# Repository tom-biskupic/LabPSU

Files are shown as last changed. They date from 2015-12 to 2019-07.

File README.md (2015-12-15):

# LabPSU
Open Source Lab Power Supply

This project is to create an open source modular lab power supply. The power supply is designed to:

* Provide between 0-15V @ 5A and 15-30V @ 3A
* Provide current limiting
* Voltage to be settable to within 1mV and current limit to 1mA resolution.
* Voltage/current readback to 1mV and 1mA with low temperature drift.
* Limit heat loss through the use of a pre-regulator. The pre-regulator uses an SCR and MOSFET arrangement to reduce noise (switches at a low frequency)
* Digitally controllable via a Raspberry PI and touch-screen interface.
* Multiple channels (designed for 3).
* Each channel is isolated and can be paralleled or put in series.
* Each channel uses its own torroidal transformer.

A Blog documenting the development of the project can be found here http://wahz.blogspot.com.au/2015/03/lab-power-supply-project.html

The major components used in the project are:

* IRFP044N N-channel MOSFET as the pass device. http://www.irf.com/product-info/datasheets/data/irfp044n.pdf
* IRF5210 P-channel MOSFET used to switch the input in the pre-regulator http://www.irf.com/product-info/datasheets/data/irf5210.pdf
* MCR-100 SCR http://www.onsemi.com/pub_link/Collateral/MCR100-D.PDF
* LT1639 Op Amps used in the control loop. http://www.linear.com/product/LT1639
* LT1716 Comparator used in the pre-regulator http://cds.linear.com/docs/en/datasheet/1716fa.pdf
* LTC2050 Op Amp used for current sense amplifier. http://www.linear.com/product/LTC2050
* AD5689R DAC with built in 2ppm/degree reference as main output voltage/current DAC. http://www.analog.com/media/en/technical-documentation/data-sheets/AD5689_5687.pdf
* AD7705 ADC used to read output voltage/current http://www.analog.com/media/en/technical-documentation/data-sheets/AD7705_7706.pdf
* ATMEGA328P Used as the main controller
* ADUM1201 dual channel isolator used to isolate the USB interface from the rest of the module http://www.analog.com/media/en/technical-documentation/data-sheets/ADuM1200_1201.pdf
* MCP2200 USB to serial converter http://www.microchip.com/wwwproducts/devices.aspx?dDocName=en546923

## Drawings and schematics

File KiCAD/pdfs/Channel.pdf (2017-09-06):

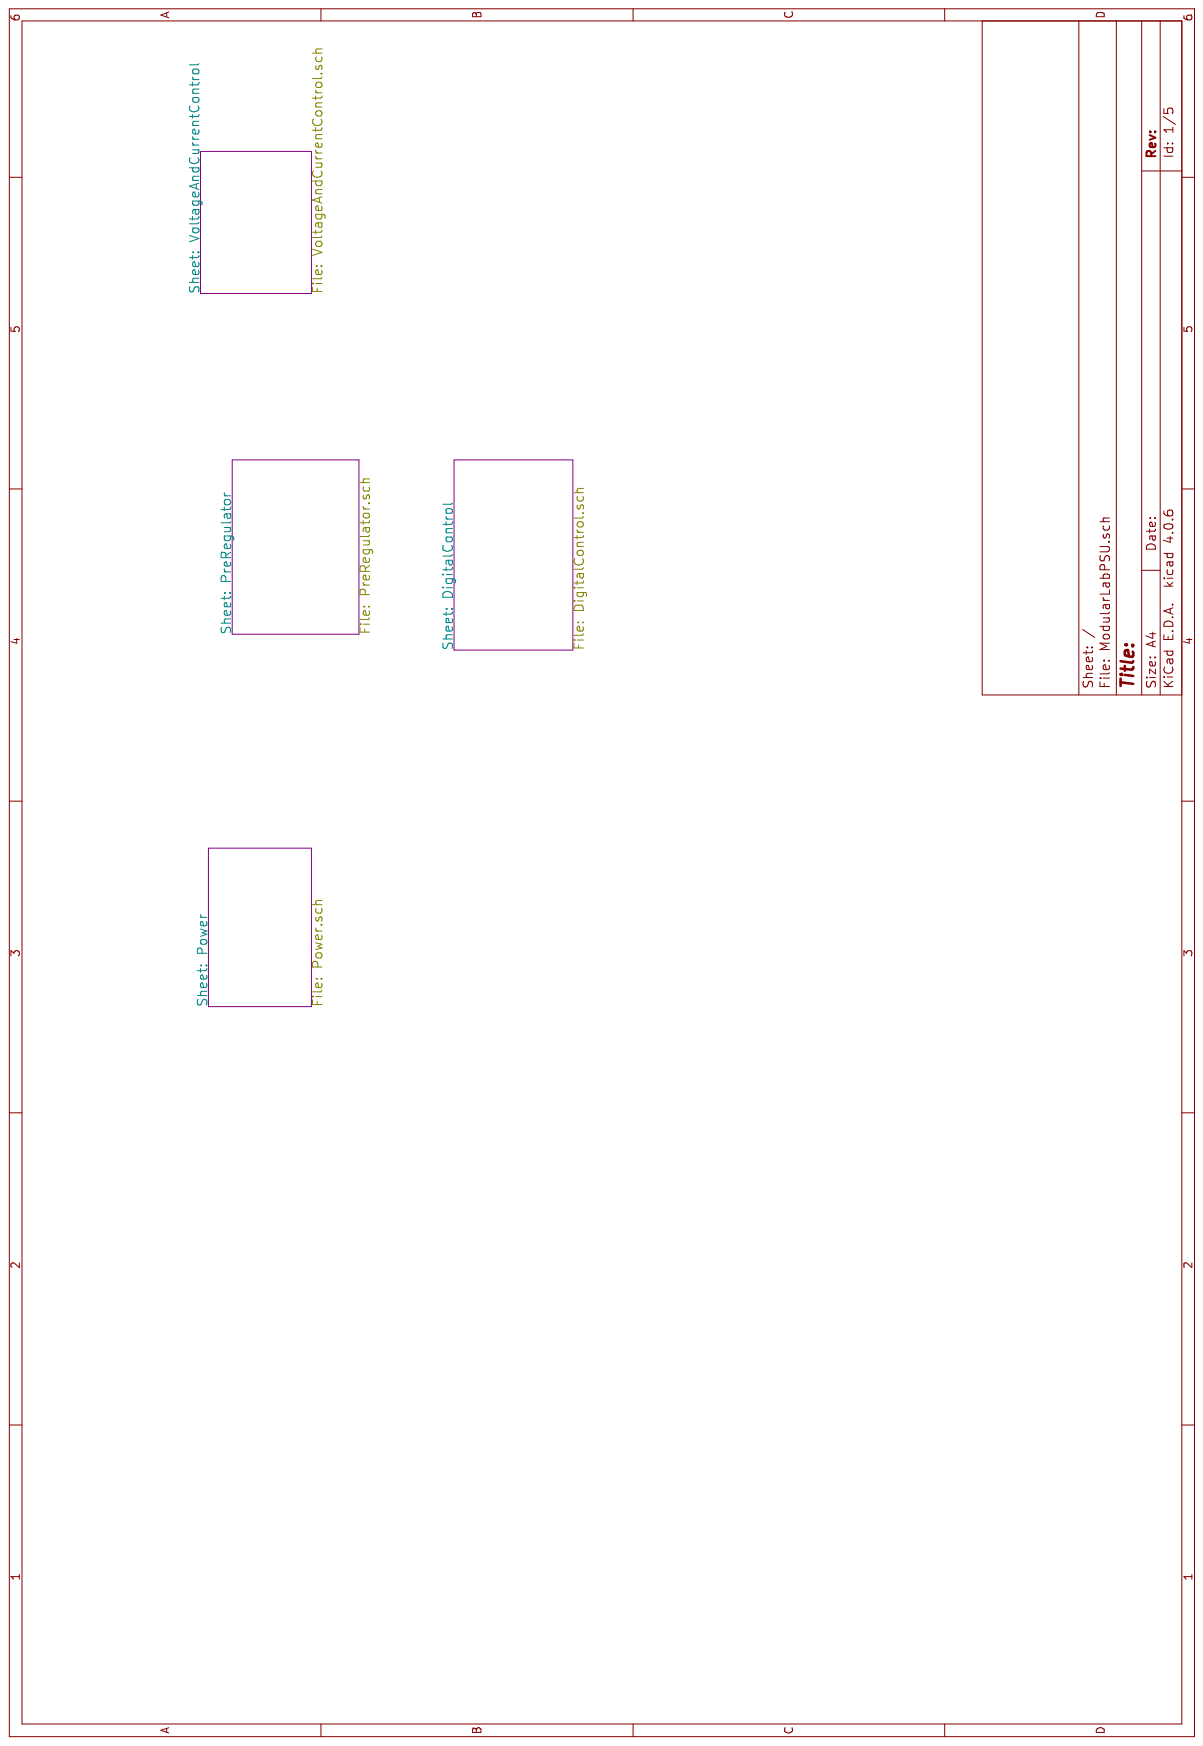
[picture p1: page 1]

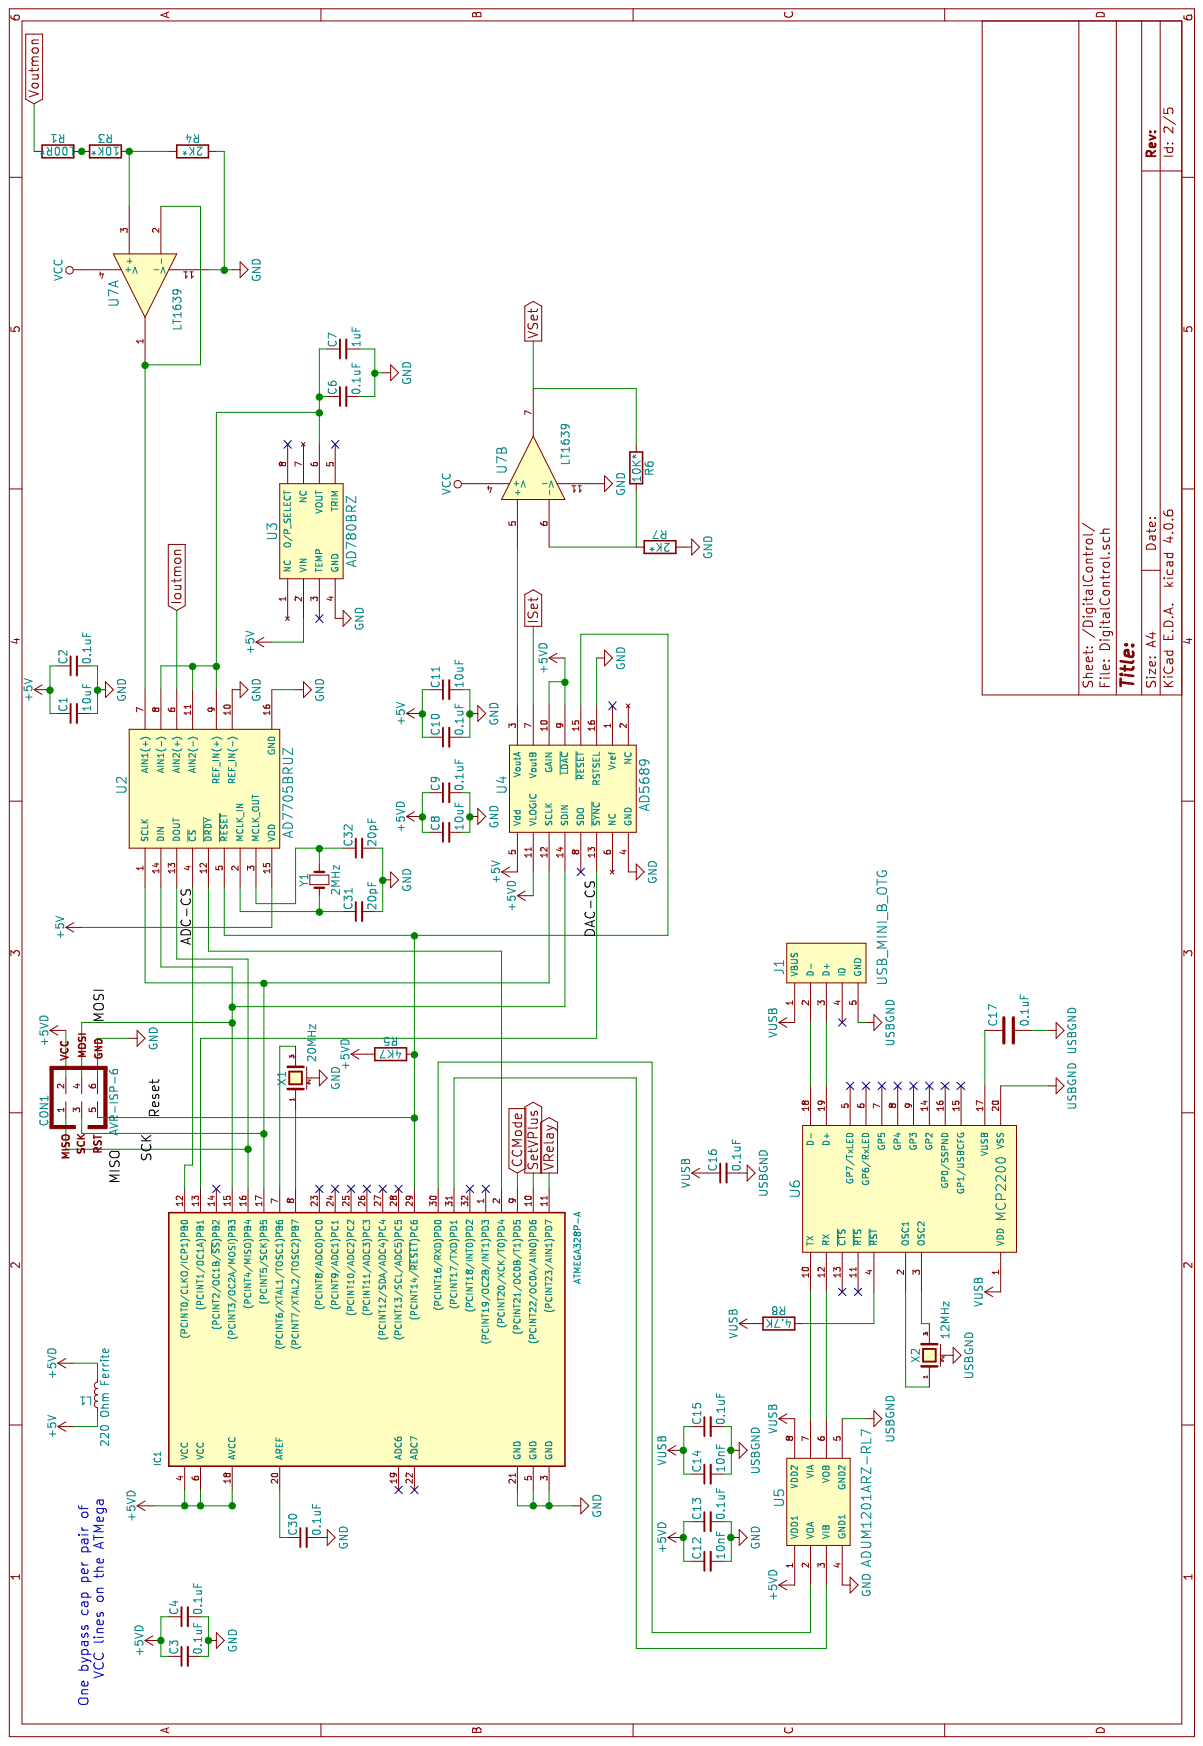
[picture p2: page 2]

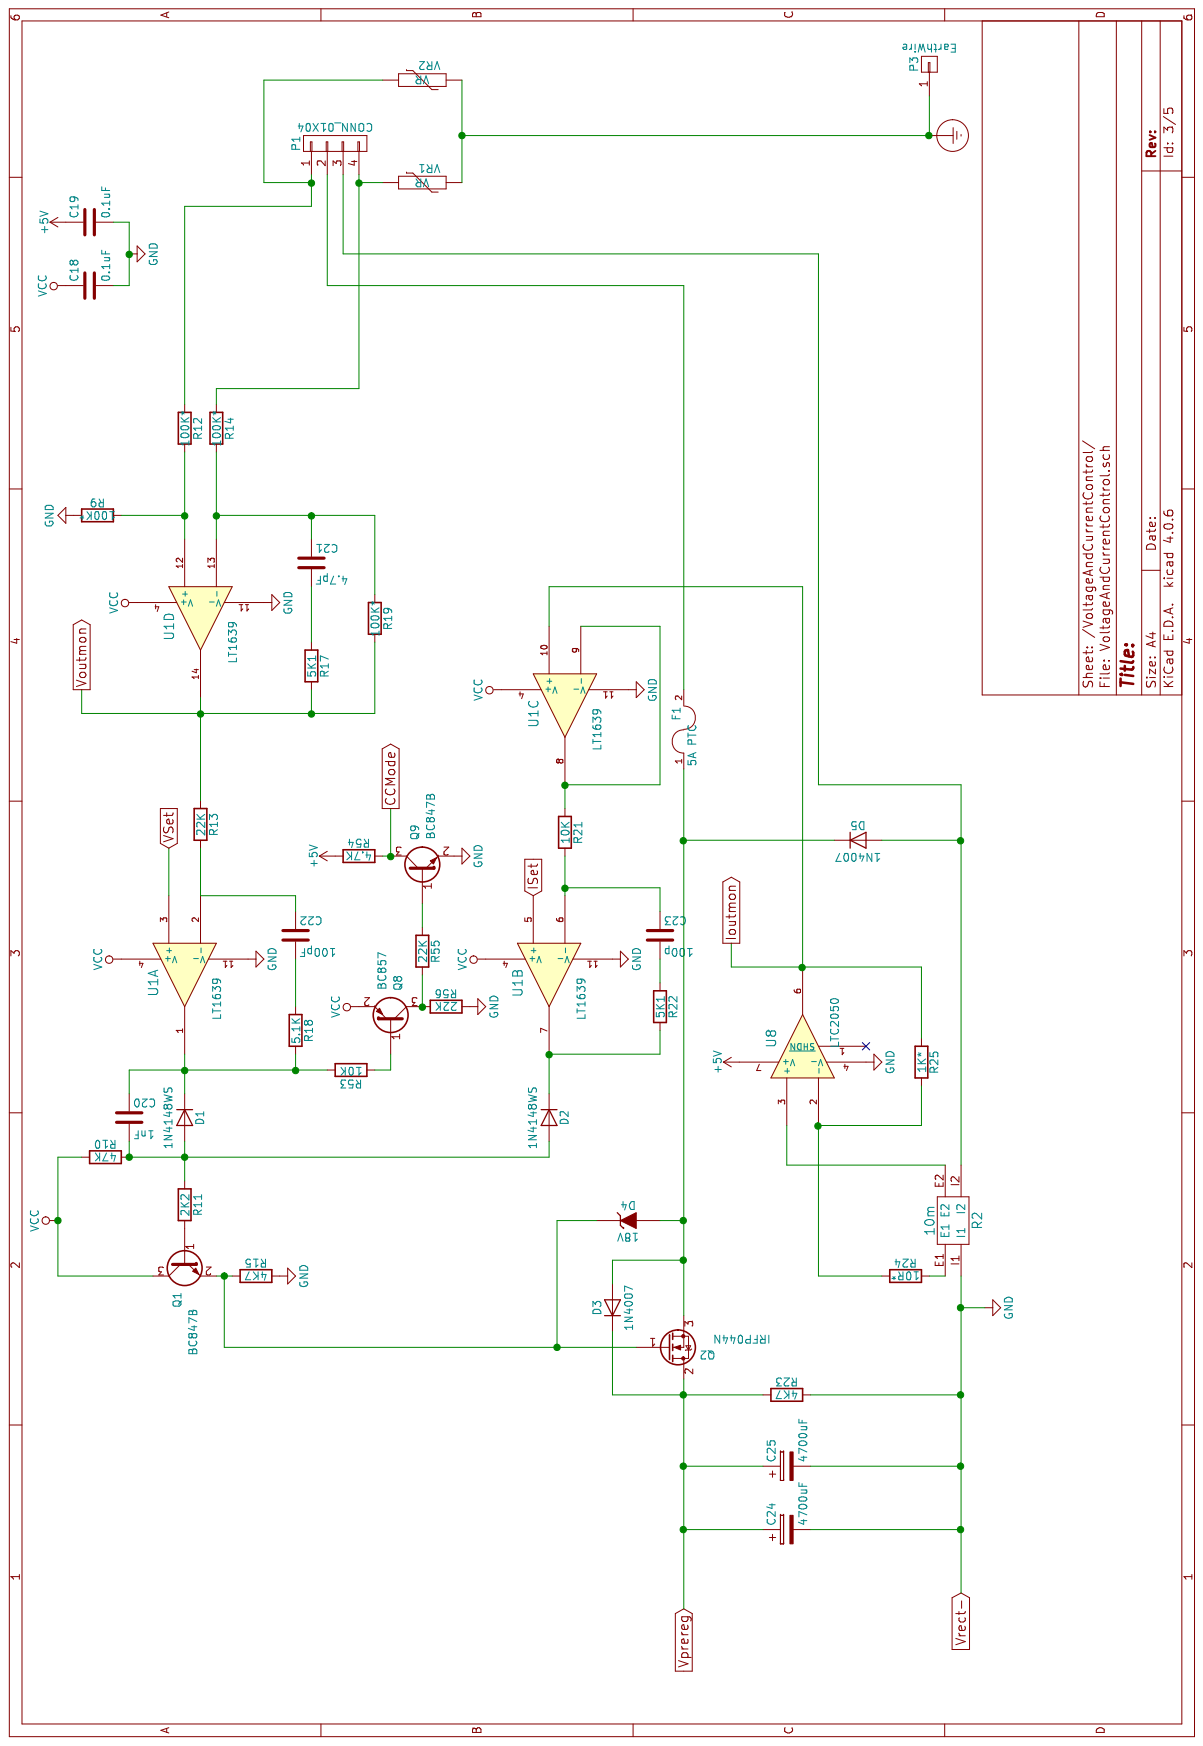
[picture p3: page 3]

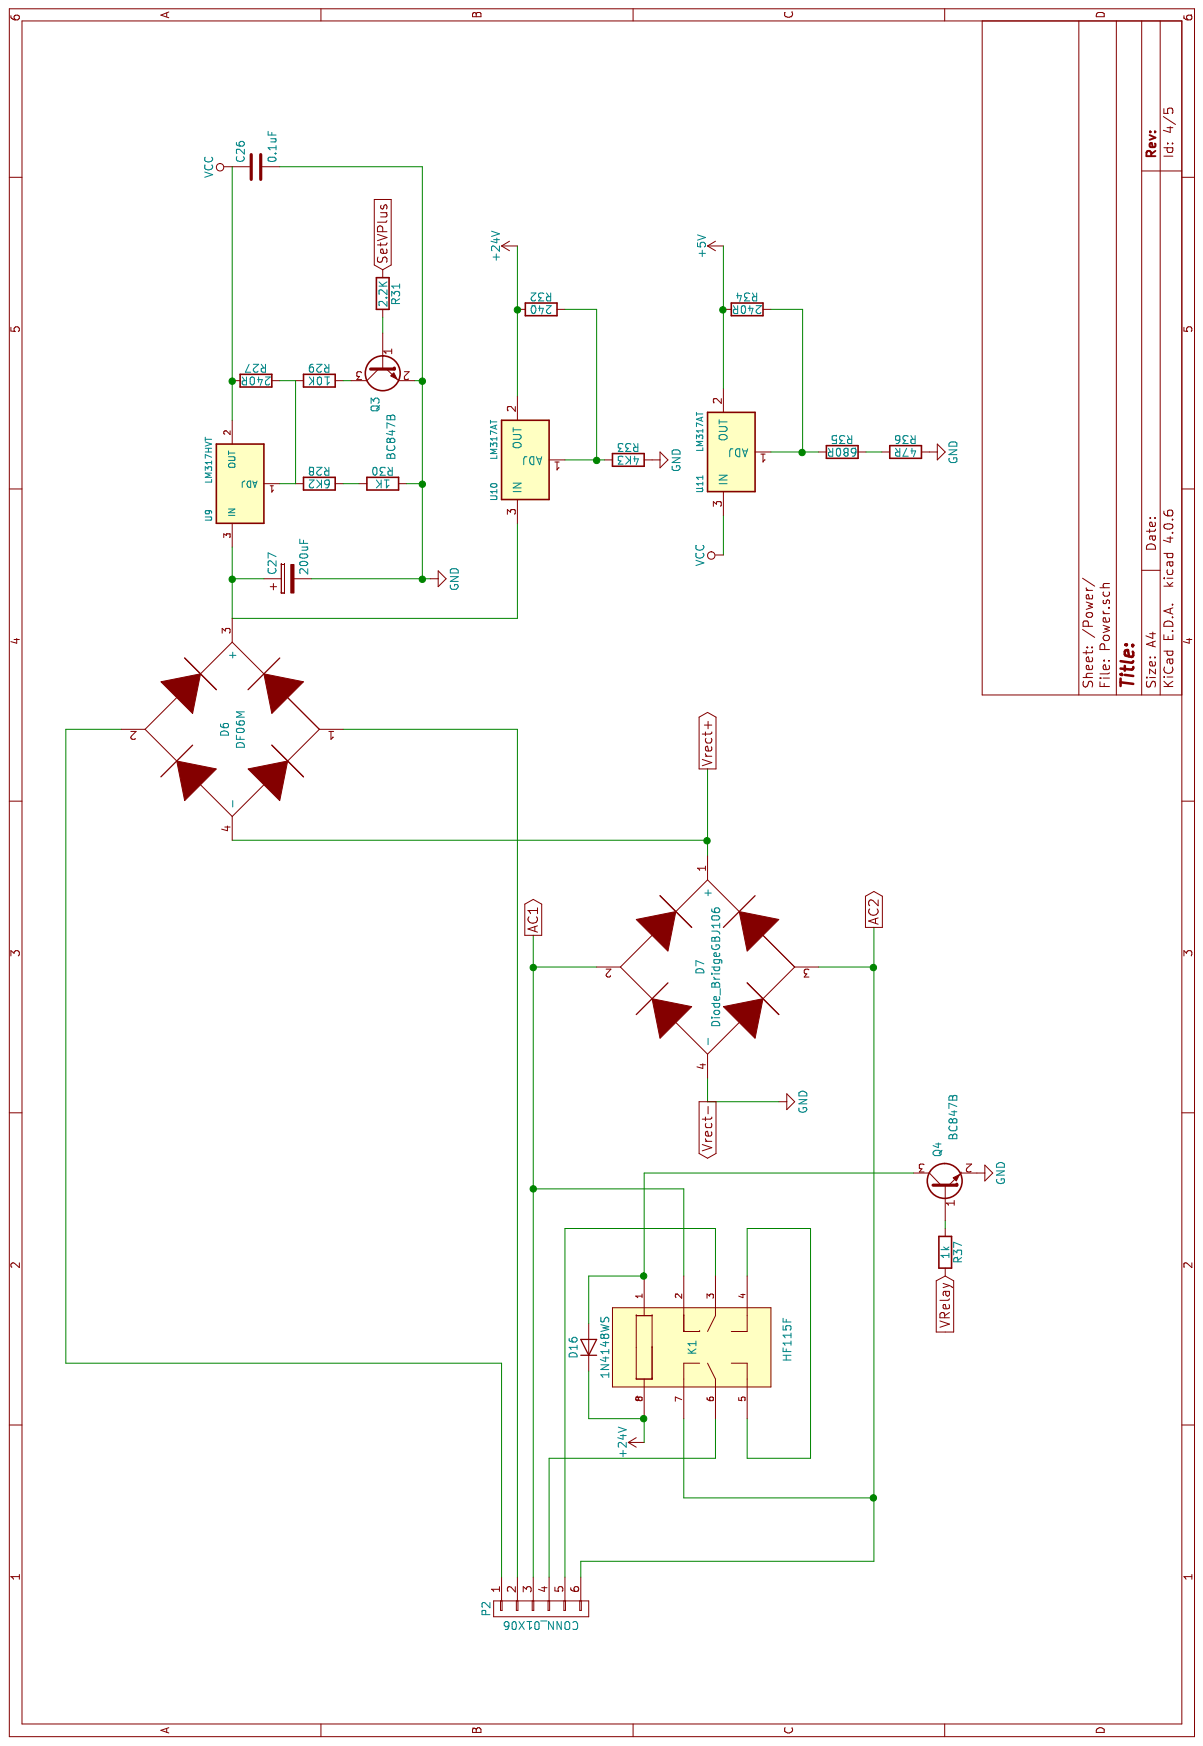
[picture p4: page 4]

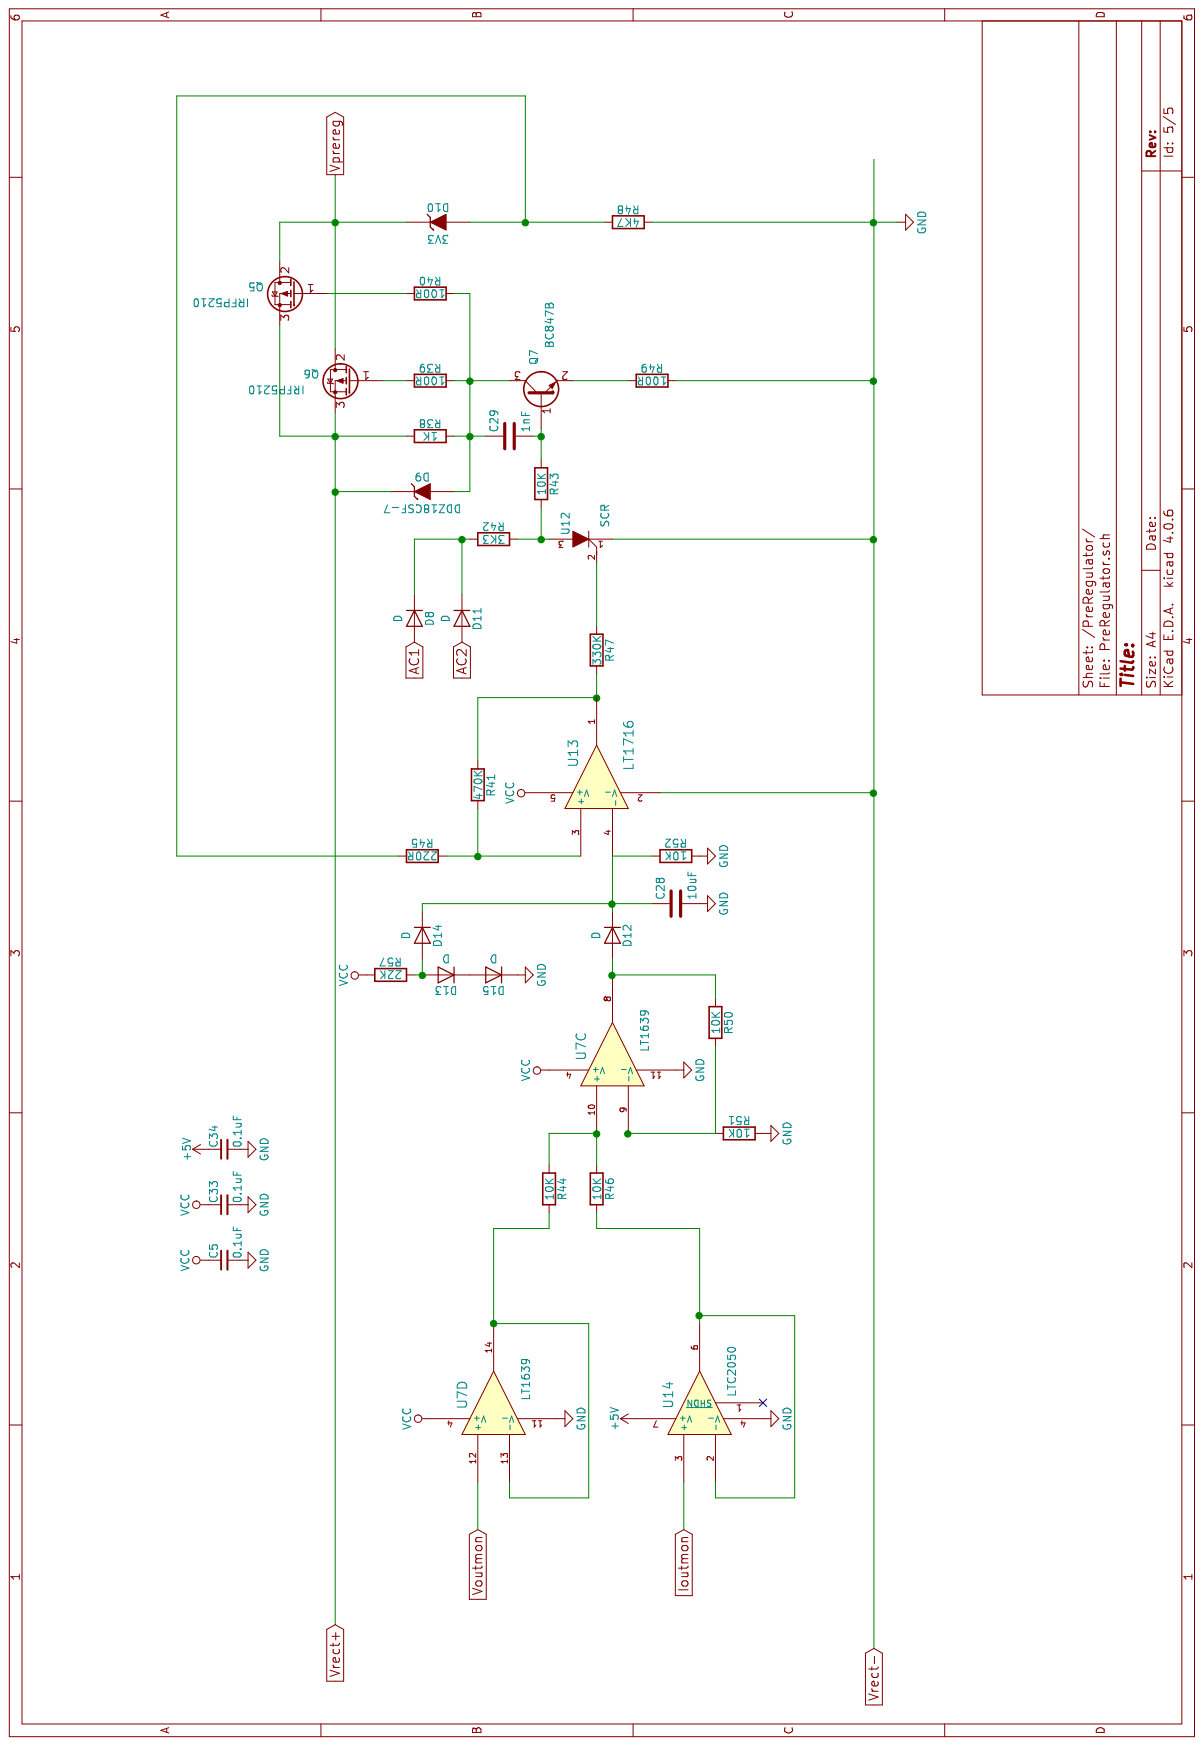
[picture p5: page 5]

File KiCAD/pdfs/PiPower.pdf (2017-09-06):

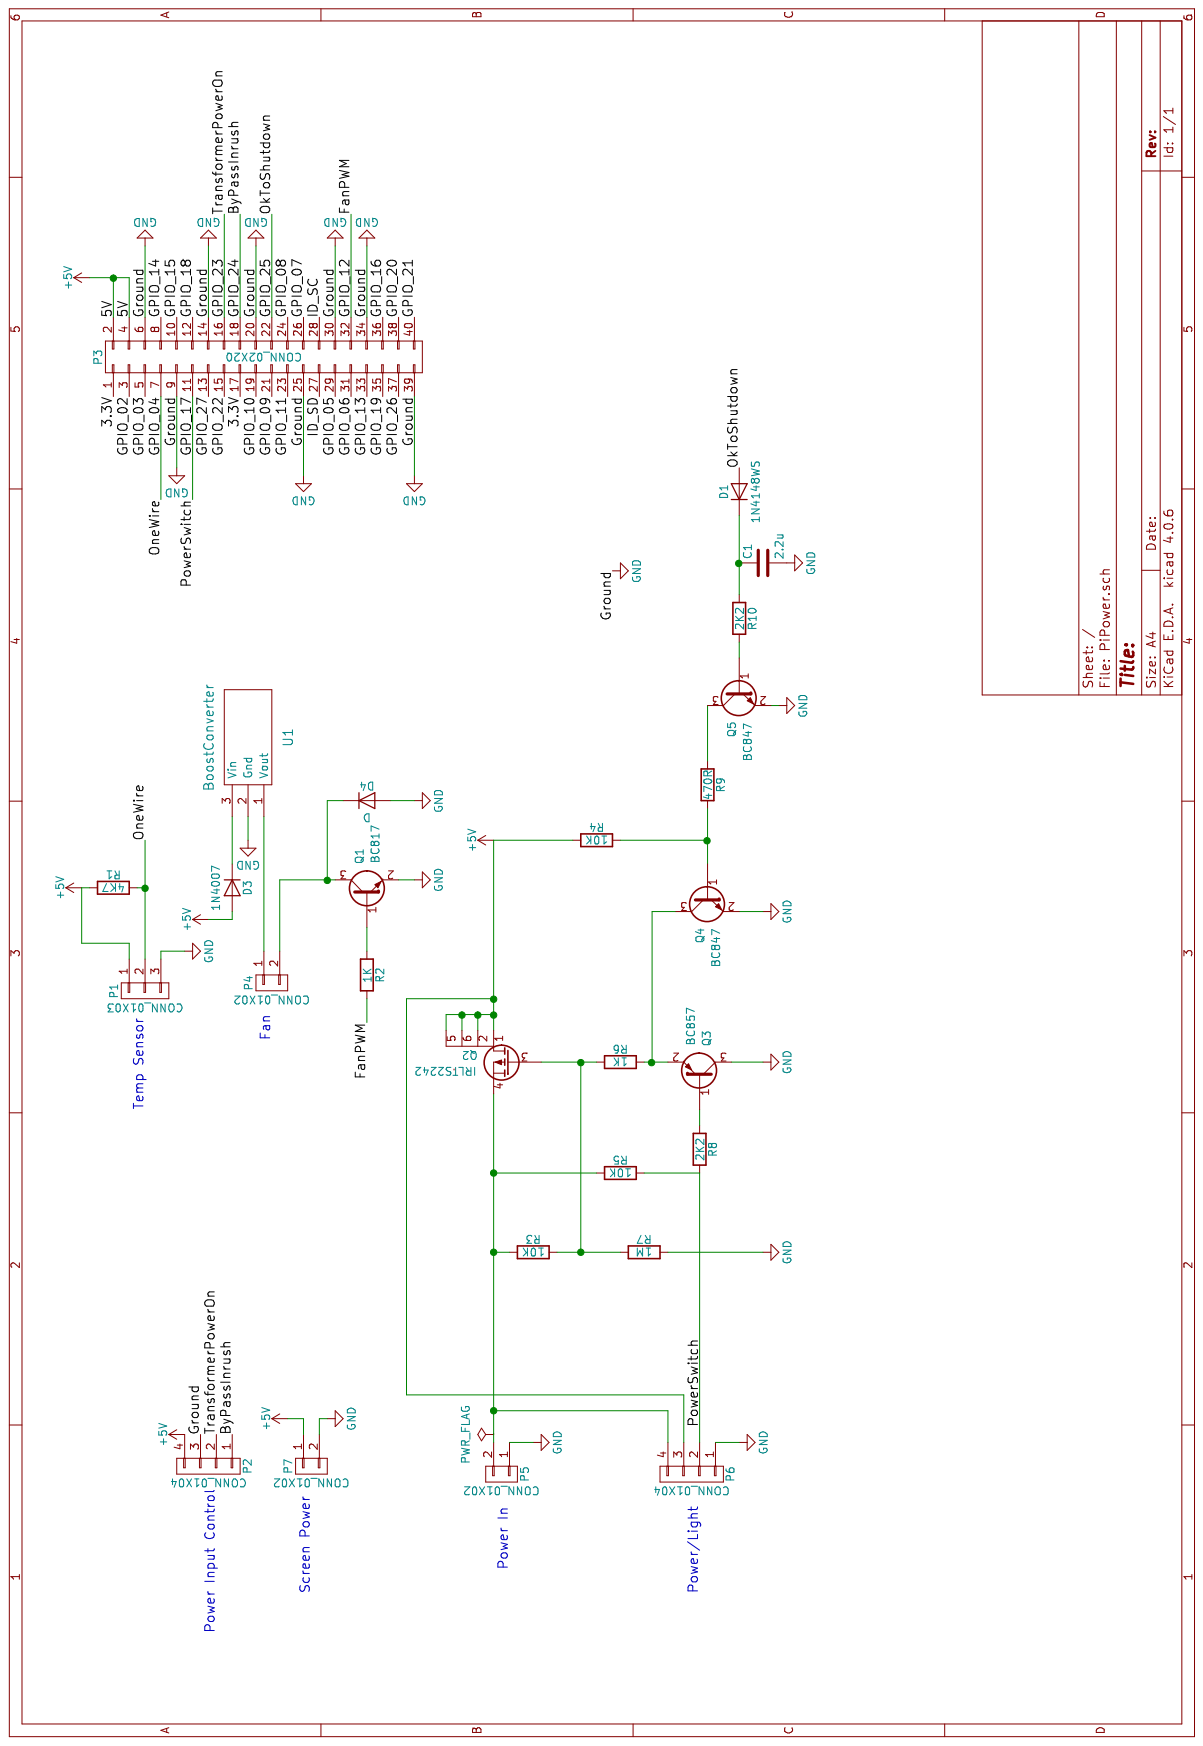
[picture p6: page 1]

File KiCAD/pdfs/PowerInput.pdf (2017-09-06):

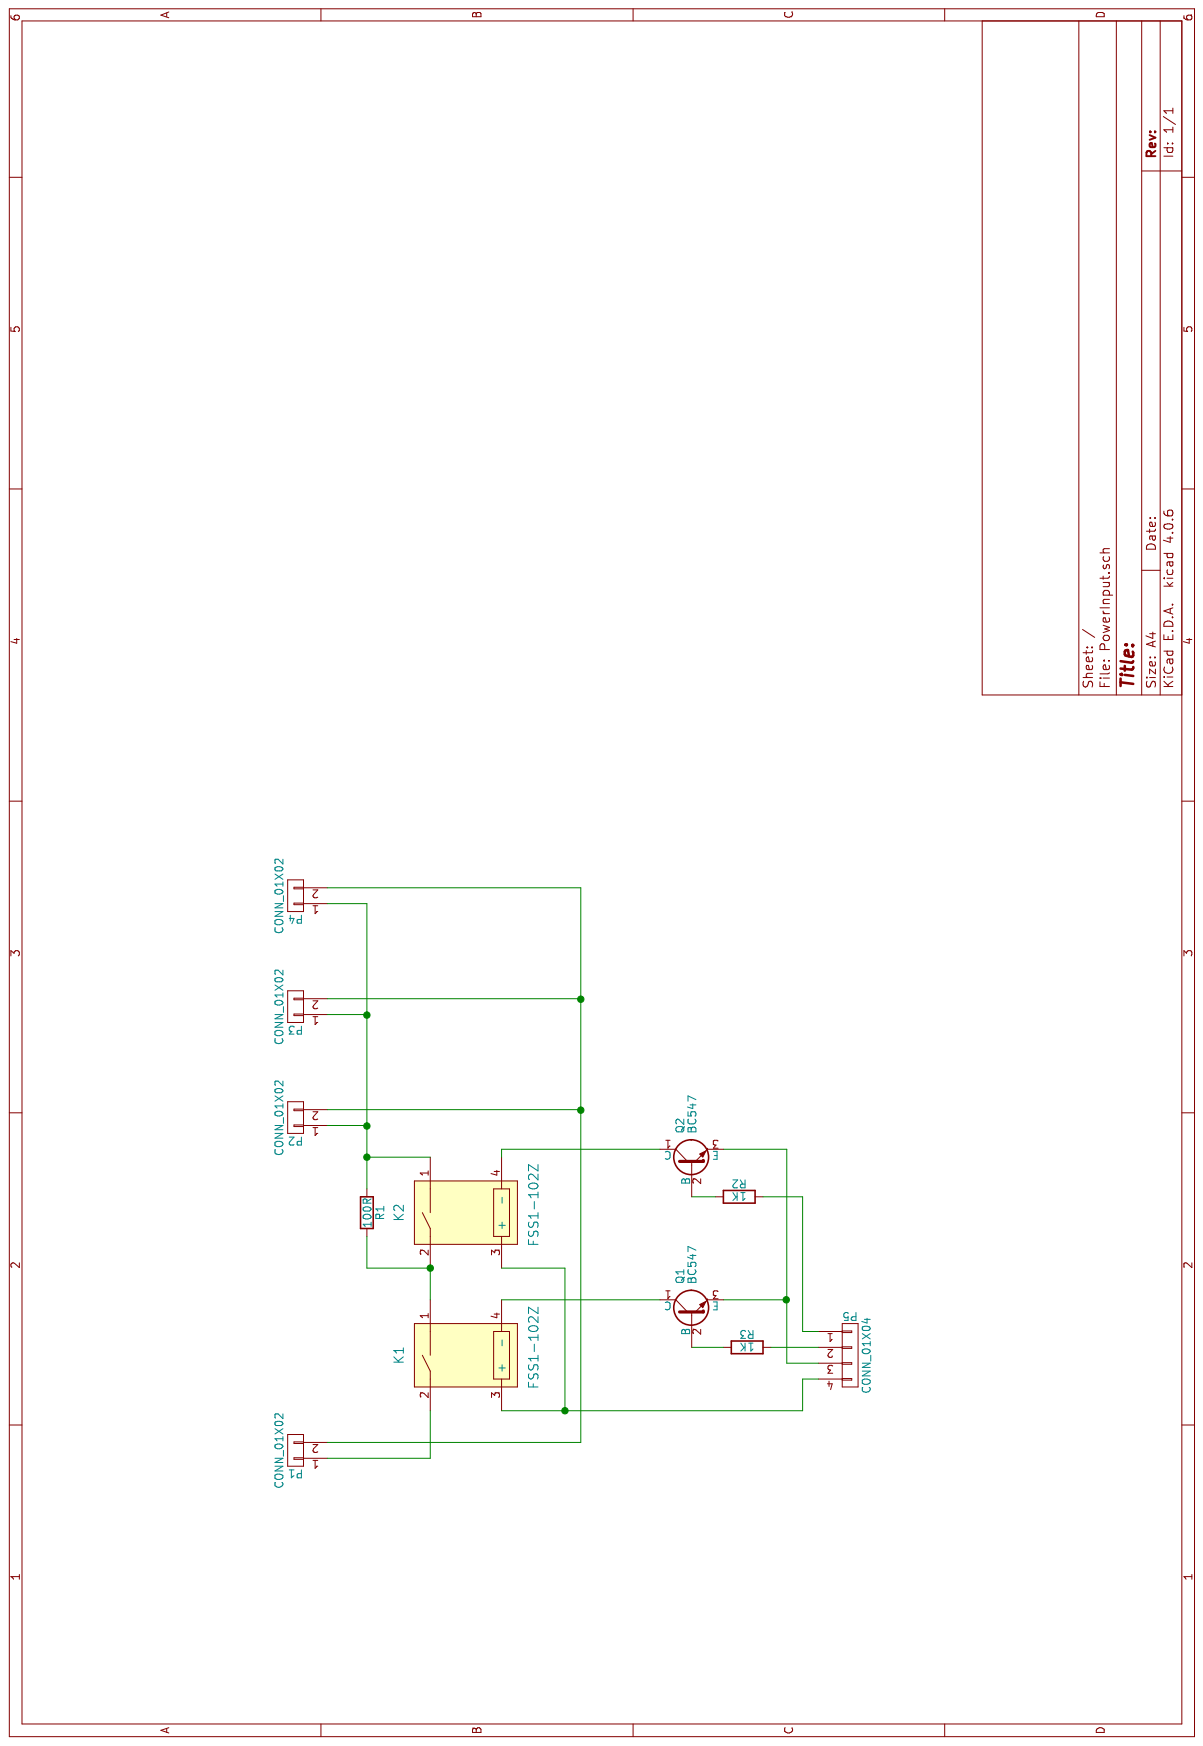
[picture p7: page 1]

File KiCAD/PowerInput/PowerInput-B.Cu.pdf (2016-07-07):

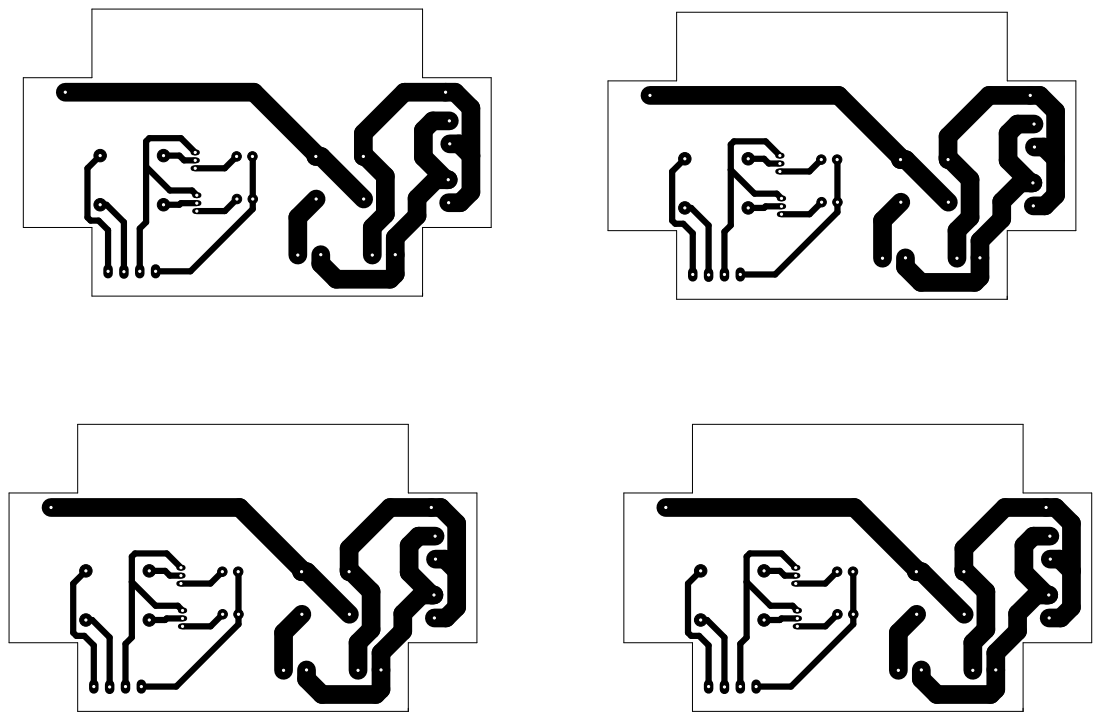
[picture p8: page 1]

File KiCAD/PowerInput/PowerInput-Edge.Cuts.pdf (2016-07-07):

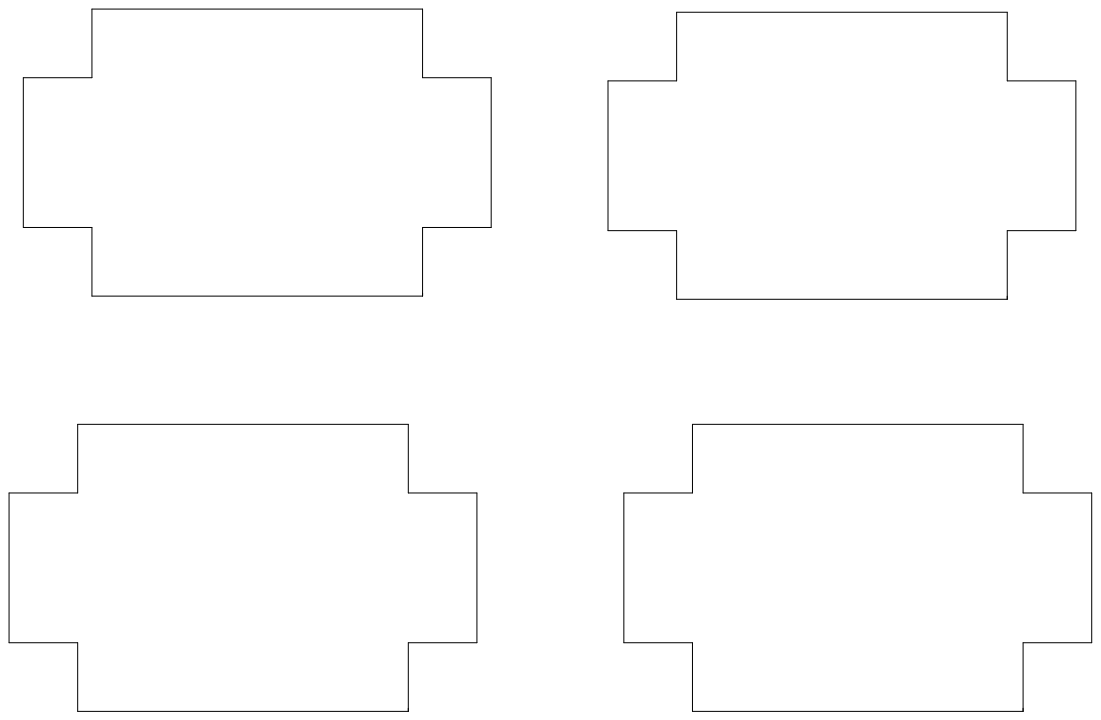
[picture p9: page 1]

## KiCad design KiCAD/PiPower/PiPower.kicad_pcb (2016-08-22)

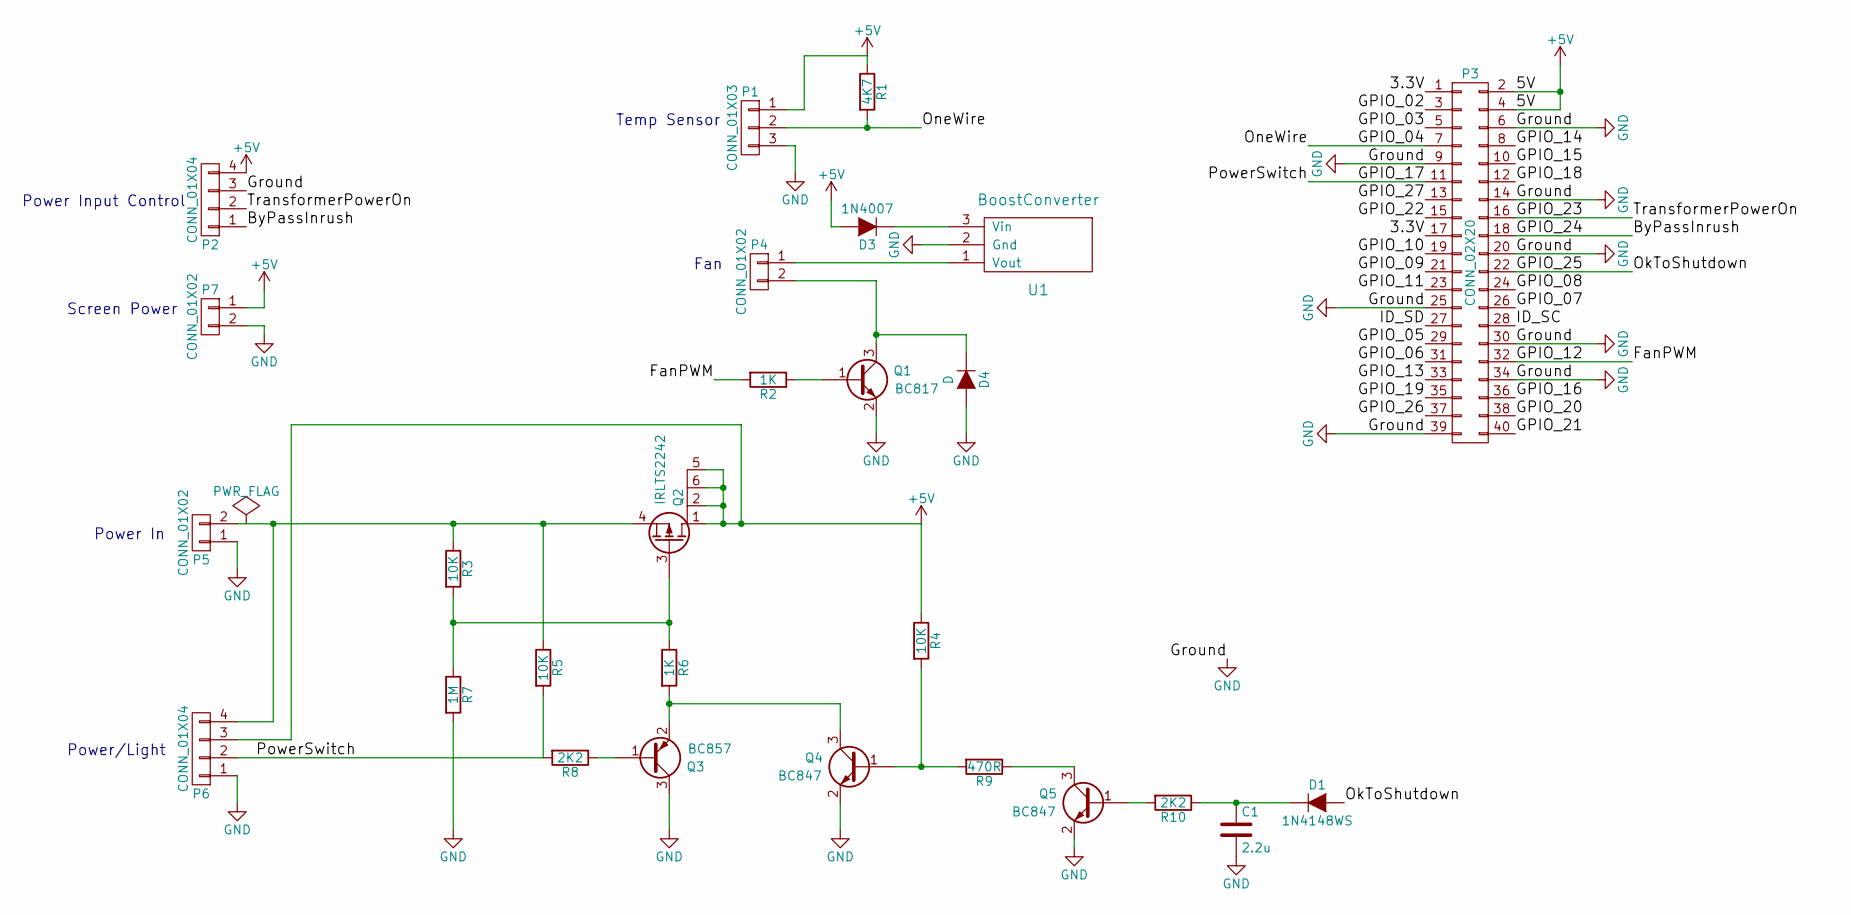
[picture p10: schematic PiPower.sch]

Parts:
C1: 2.2u; C_0805
D1: 1N4148WS; SOD-323
D3: 1N4007; Diode_DO-41_SOD81_Horizontal_RM10
D4: D; SOD-323
P1: CONN_01X03; ThreePinSmall
P2, P6: CONN_01X04; PINHeader1-4
P3: CONN_02X20; Pin_Header_Straight_2x20
P4: CONN_01X02; TwoPinSmall
P5: CONN_01X02; WCON-2PIN
P7: CONN_01X02; Pin_Header_Straight_1x02
Q1: BC817; SOT-23
Q2: IRLTS2242
Q3: BC857; SOT-23
Q4, Q5: BC847; SOT-23
R1: 4K7; R_0805
R2, R6: 1K; R_0805
R3, R4, R5: 10K; R_0805
R7: 1M; R_0805
R8, R10: 2K2; R_0805
R9: 470R; R_0805
U1: BoostConverter

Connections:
+5V: D3.2 (A), P1.1, P2.4, P3.2, P3.4, P6.3, P7.1, Q2.1 (D), Q2.2 (D), Q2.5 (D), Q2.6 (D), R1.1, R4.1
/3.3V: P3.1, P3.17
/ByPassInrush: P2.1, P3.18
/FanPWM: P3.32, R2.2
/GPIO_02: P3.3
/GPIO_03: P3.5
/GPIO_04: P1.2, P3.7, R1.2
/GPIO_05: P3.29
/GPIO_06: P3.31
/GPIO_07: P3.26
/GPIO_08: P3.24
/GPIO_09: P3.21
/GPIO_10: P3.19
/GPIO_11: P3.23
/GPIO_13: P3.33
/GPIO_14: P3.8
/GPIO_15: P3.10
/GPIO_16: P3.36
/GPIO_17: P3.11, P6.2, R5.2, R8.2
/GPIO_18: P3.12
/GPIO_19: P3.35
/GPIO_20: P3.38
/GPIO_21: P3.40
/GPIO_22: P3.15
/GPIO_23: P2.2, P3.16
/GPIO_25: D1.2 (A), P3.22
/GPIO_26: P3.37
/GPIO_27: P3.13
/ID_SC: P3.28
/ID_SD: P3.27
GND: C1.2, D4.2 (A), P1.3, P2.3, P3.6, P3.9, P3.14, P3.20, P3.25, P3.30, P3.34, P3.39, P5.1, P6.1, P7.2, Q1.2 (E), Q3.3 (C), Q4.2 (E), Q5.2 (E), R7.2, U1.2 (Gnd)
unnamed: C1.1, D1.1 (K), R10.1
unnamed: D3.1 (K), U1.3 (Vin)
unnamed: D4.1 (K), P4.2, Q1.3 (C)
unnamed: P4.1, U1.1 (Vout)
unnamed: P5.2, P6.4, Q2.4 (S), R3.1, R5.1
unnamed: Q1.1 (B), R2.1
unnamed: Q2.3 (G), R3.2, R6.1, R7.1
unnamed: Q3.1 (B), R8.1
unnamed: Q3.2 (E), Q4.3 (C), R6.2
unnamed: Q4.1 (B), R4.2, R9.2
unnamed: Q5.1 (B), R10.2
unnamed: Q5.3 (C), R9.1

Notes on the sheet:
Power/Light
Power In
Power Input Control
Temp Sensor
Fan
Screen Power

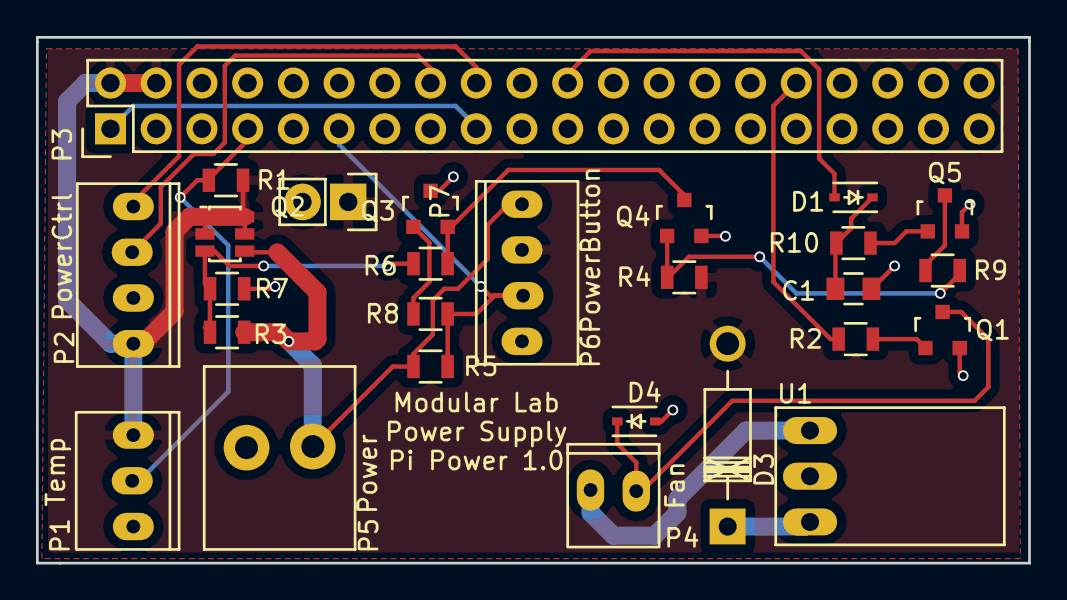
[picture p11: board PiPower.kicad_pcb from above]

Board: 2 copper layers, 55.1 x 29.2 mm, 27 parts (0 on the bottom side), 21 nets.

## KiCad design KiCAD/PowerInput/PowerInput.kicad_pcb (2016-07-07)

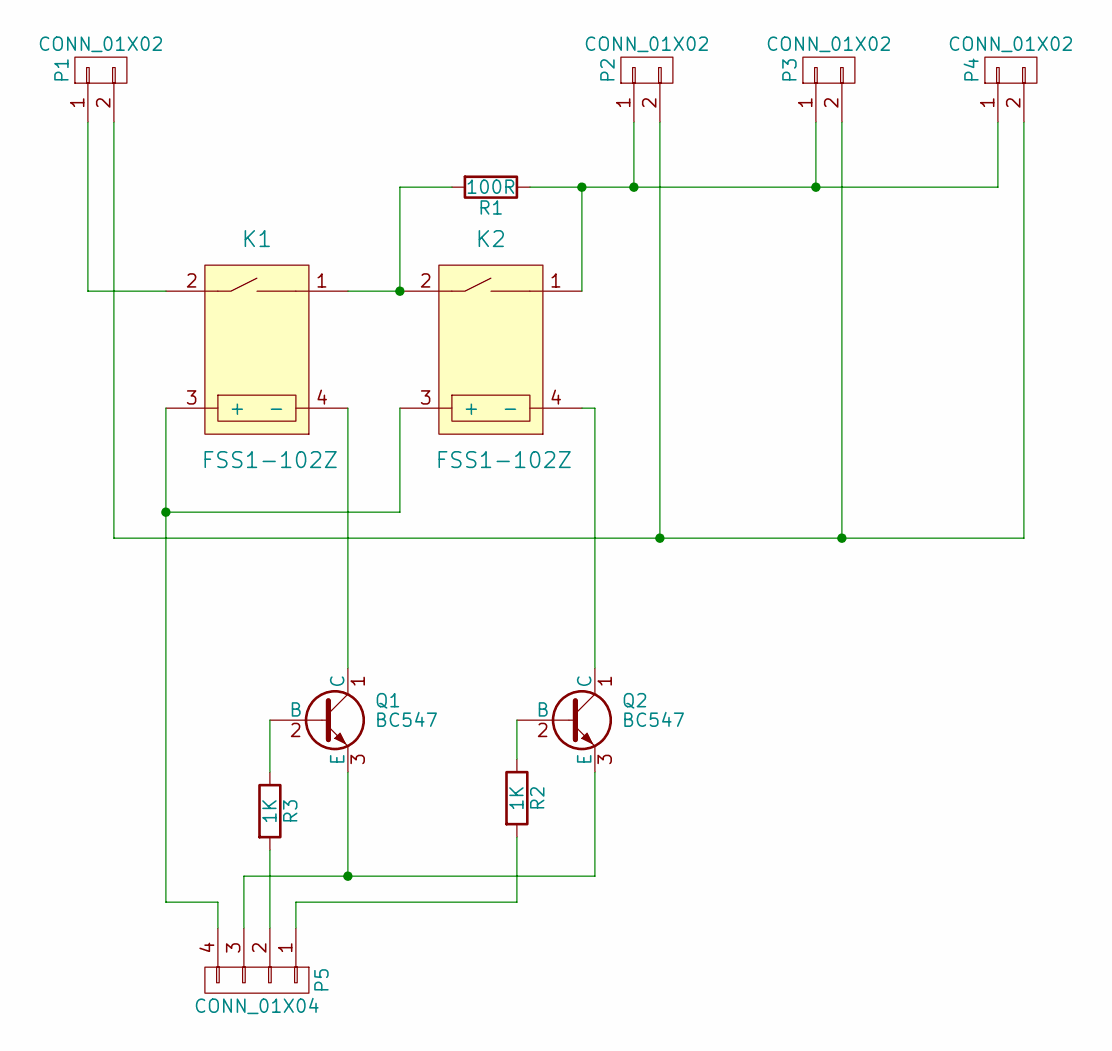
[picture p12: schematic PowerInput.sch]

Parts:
K1, K2: FSS1-102Z
P1, P2, P3, P4: CONN_01X02; WCON-2PIN
P5: CONN_01X04; PINHeader1-4
Q1, Q2: BC547; TO-92_Inline_Narrow_Oval
R1: 100R; Resistor_Ceramic_Horizontal_L50mm-W14mm-H13mm-p60mm
R2, R3: 1K; Resistor_Horizontal_RM10mm

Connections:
unnamed: K1.1, K2.2, R1.2
unnamed: K1.2, P1.1
unnamed: K1.3 (+), K2.3 (+), P5.4
unnamed: K1.4 (-), Q1.1 (C)
unnamed: K2.1, P2.1, P3.1, P4.1, R1.1
unnamed: K2.4 (-), Q2.1 (C)
unnamed: P1.2, P2.2, P3.2, P4.2
unnamed: P5.1, R2.2
unnamed: P5.2, R3.2
unnamed: P5.3, Q1.3 (E), Q2.3 (E)
unnamed: Q1.2 (B), R3.1
unnamed: Q2.2 (B), R2.1

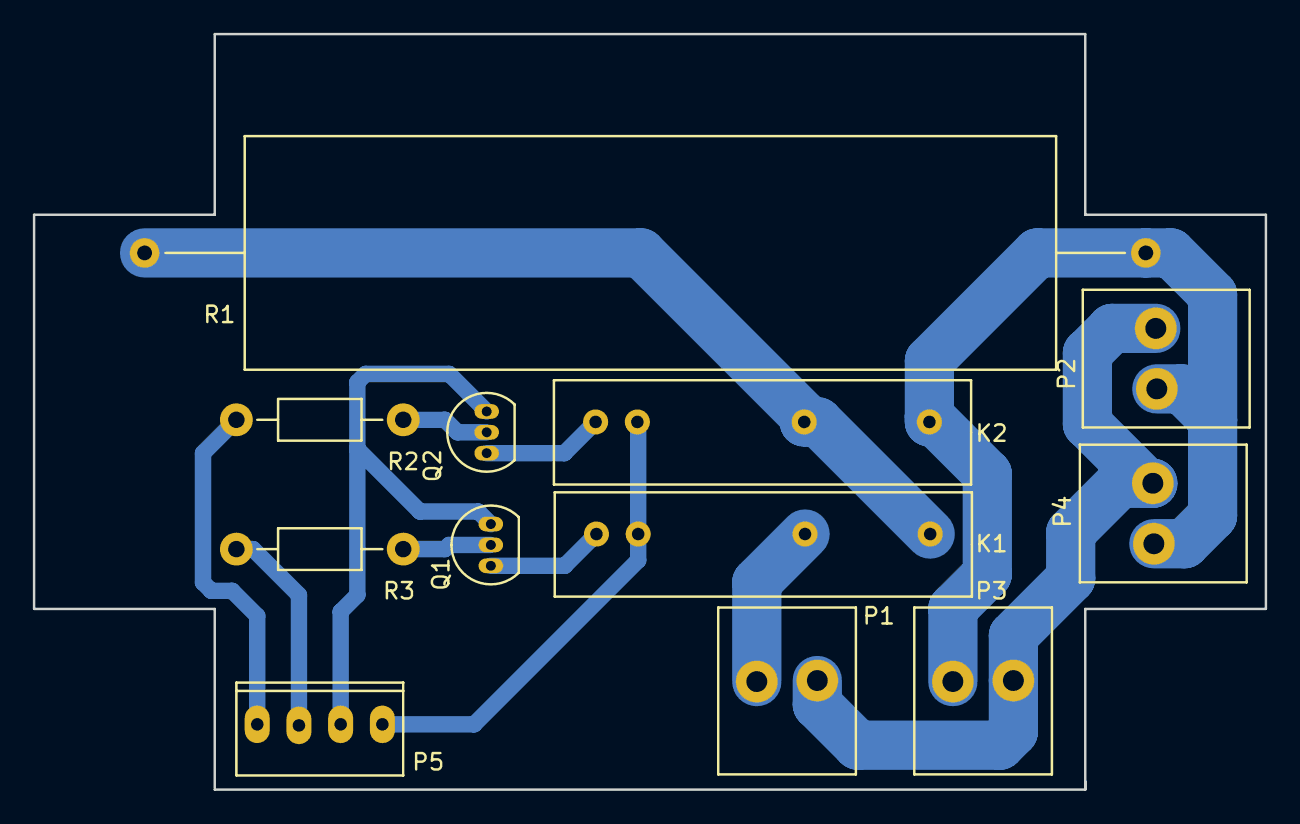
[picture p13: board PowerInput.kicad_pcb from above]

Board: 2 copper layers, 75.0 x 46.0 mm, 12 parts (0 on the bottom side), 12 nets.

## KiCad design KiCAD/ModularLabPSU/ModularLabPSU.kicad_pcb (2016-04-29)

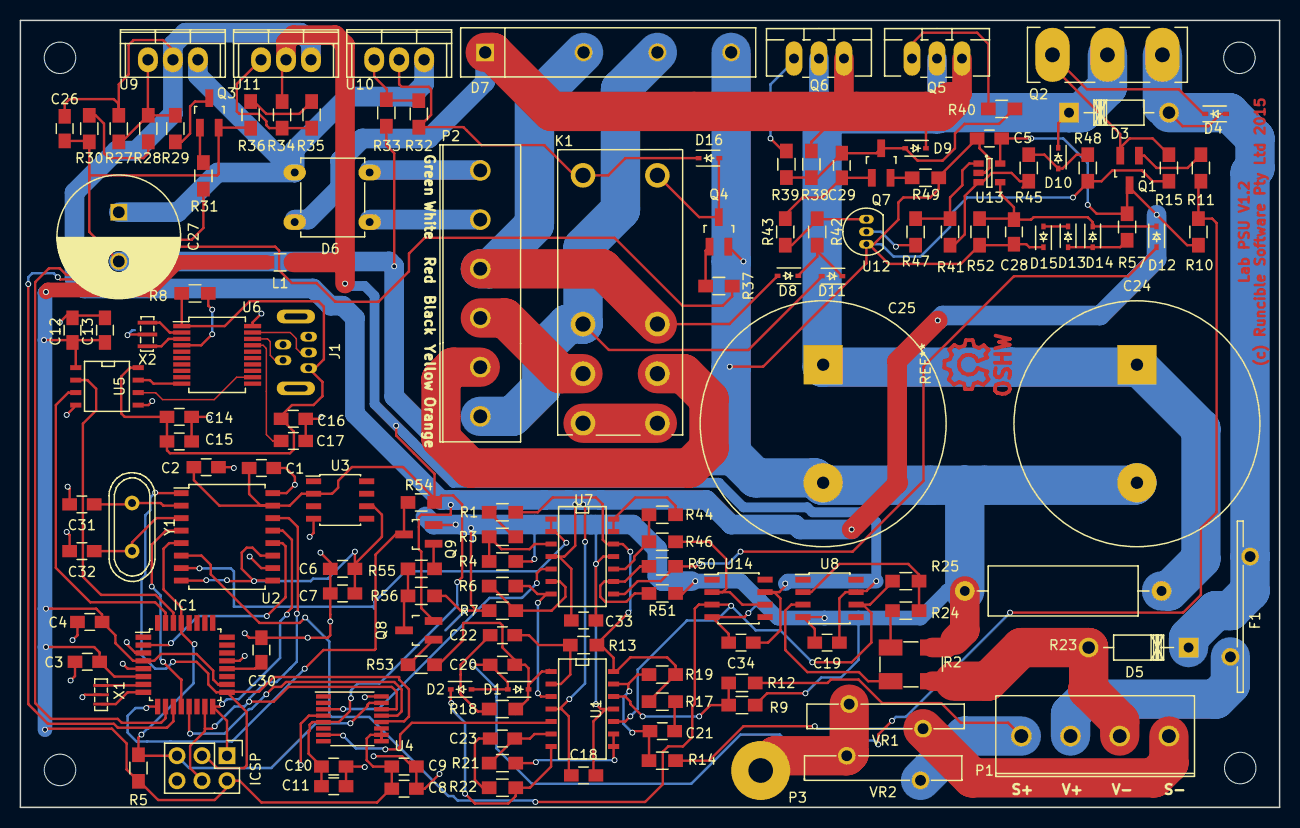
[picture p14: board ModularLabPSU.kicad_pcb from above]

Board: 2 copper layers, 128.0 x 80.0 mm, 141 parts (0 on the bottom side), 105 nets.

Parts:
C1, C8, C11, C28: 10uF; C_0805_HandSoldering
C2, C3, C4, C5, C6, C9, C10, C13, C15, C16, C17, C18, C19, C26, C30, C33, C34: 0.1uF; C_0805_HandSoldering
C7: 1uF; C_0805_HandSoldering
C12, C14: 10nF; C_0805_HandSoldering
C20, C29: 1nF; C_0805_HandSoldering
C21: 4.7pF; C_0805_HandSoldering
C22: 100pF; C_0805_HandSoldering
C23: 100p; C_0805_HandSoldering
C24, C25: 4700uF; RS_C4700uF_63V
C27: 200uF; C_Radial_D12.5_L25_P5
C31, C32: 20pF; C_0805_HandSoldering
D1, D2, D16: 1N4148WS; SOD-323
D3, D5: 1N4007; Diode_DO-41_SOD81_Horizontal_RM10
D4: 18V; SOD-323
D6: DF06M; DiodesIncDF06M
D7: Diode_BridgeGBJ106; DIODE_BRIDGE_GBJ1506
D8, D11, D12, D13, D14, D15: D; SOD-323
D9: DDZ18CSF-7; SOD-323
D10: 3V3; SOD-323
F1: 5A PTC; BOURNSMF-R500
IC1: ATMEGA328P-A; TQFP-32_7x7mm_Pitch0.8mm
ICSP: AVR-ISP-6; Pin_Header_Straight_2x03
J1: USB_MINI_B_OTG; MOLEX-USB-OTG-MINI-STRAIGHT
K1: HF115F
L1: 220 Ohm Ferrite; R_0805_HandSoldering
P1: CONN_01X04; RS5mmClampTerminal
P2: CONN_01X06; 6PosRS5mmClampTerminal
P3: EarthWire; SolderWirePad_single_2-5mmDrill
Q1, Q3, Q4, Q7, Q9: BC847B; SOT-23_Handsoldering
Q2: IRFP044N; TO-247_Vertical_Neutral123_largePads
Q5, Q6: IRFP5210; TO-220_Neutral123_Vertical_LargePads
Q8: BC857; SOT-23_Handsoldering
R1, R39, R40, R49: 100R; R_0805_HandSoldering
R2: 10m; VCS1625
R3, R6, R21, R29, R43, R44, R46, R50, R51, R52, R53: 10K; R_0805_HandSoldering
R4, R7: 2K; R_0805_HandSoldering
R5, R15, R48: 4K7; R_0805_HandSoldering
R8, R54: 4.7K; R_0805_HandSoldering
R9, R12, R14, R19: 100K*; R_0805_HandSoldering
R10: 47K; R_0805_HandSoldering
R11: 2K2; R_0805_HandSoldering
R13, R55, R56, R57: 22K; R_0805_HandSoldering
R17, R22: 5K1; R_0805_HandSoldering
R18: 5.1K; R_0805_HandSoldering
R23: 4K7; Resistor_Horizontal_RM20mm
R24: 10R; R_0805_HandSoldering
R25, R30, R38: 1K; R_0805_HandSoldering
R27, R34: 240R; R_0805_HandSoldering
R28: 6K2; R_0805_HandSoldering
R31: 2.2K; R_0805_HandSoldering
R32: 240; R_0805_HandSoldering
R33: 4K3; R_0805_HandSoldering
R35: 680R; R_0805_HandSoldering
R36: 47R; R_0805_HandSoldering
R37: 1k; R_0805_HandSoldering
R41: 470K; R_0805_HandSoldering
R42: 3K3; R_0805_HandSoldering
R45: 220R; R_0805_HandSoldering
R47: 330K; R_0805_HandSoldering
U1, U7: LT1639; SOIC-14_N
U2: AD7705BRUZ; SOIC-16_7.5x10.3mm_Pitch1.27mm
U3: AD780BRZ; SOIC-8_3.9x4.9mm_Pitch1.27mm
U4: AD5689; TSSOP-16_4.4x5mm_Pitch0.65mm
U5: ADUM1201ARZ-RL7; SOIC-8-N
U6: MCP2200; SSOP-20_5.3x7.2mm_Pitch0.65mm
U8, U14: LTC2050; SOIC-8_3.9x4.9mm_Pitch1.27mm
U9: LM317HVT; TO-220
U10, U11: LM317AT; TO-220
U12: SCR; TO-92_Inline_Narrow_Oval
U13: LT1716; SOT-23-5
VR1, VR2: VR; V275LA20AP
X1: 20MHz; CSTCE_V
X2: 12MHz; CSTCE_G
Y1: 2MHz; Crystal_HC49-U_Vertical

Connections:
+5V: C1.1, C2.1, C10.1, C11.1, C19.1, C34.1, L1.1, R34.1, R54.1, U2.15, U3.2, U4.5, U8.7, U11.2, U14.7
+5VD: C3.1, C4.1, C8.1, C9.1, C12.1, C13.1, IC1.4, IC1.6, IC1.18, ICSP.2, L1.2, R5.1, U4.9, U4.10, U4.11, U5.1
+24V: D16.1, K1.8, R32.1, U10.2
/DigitalControl/ADC-CS: IC1.12, U2.4
/DigitalControl/DAC-CS: IC1.13, U4.13
/DigitalControl/MISO: IC1.16, ICSP.1, U2.13
/DigitalControl/MOSI: IC1.15, ICSP.4, U2.14, U4.14
/DigitalControl/Reset: IC1.29, ICSP.5, R5.2, U2.5, U4.15
/DigitalControl/SCK: IC1.17, ICSP.3, U2.1, U4.12
AC1: D7.2, D8.2, K1.2, P2.3
AC2: D7.3, D11.2, K1.7, P2.6
CCMode: IC1.9, Q9.3, R54.2
Earth_Protective: P3.1, VR1.2, VR2.2
ISet: U1.5, U4.7
Ioutmon: R25.1, U1.10, U2.6, U8.6, U14.3
unnamed: C6.1, C7.1, U2.8, U2.9, U2.11, U3.6
unnamed: C17.1, U6.17
unnamed: C20.1, D1.1, R18.2, R53.2, U1.1
unnamed: C20.2, D1.2, D2.2, R10.2, R11.1
unnamed: C21.1, R14.2, R19.1, U1.13
unnamed: C21.2, R17.1
unnamed: C22.1, R13.2, U1.2
unnamed: C22.2, R18.1
unnamed: C23.1, R21.2, U1.6
unnamed: C23.2, R22.1
unnamed: C27.1, D6.3, U9.3, U10.3
unnamed: C28.1, D12.1, D14.1, R52.1, U13.4
unnamed: C29.1, D9.2, Q7.3, R38.2, R39.2, R40.2
unnamed: C29.2, Q7.1, R43.1
unnamed: C30.1, IC1.20
unnamed: C31.1, U2.2, Y1.1
unnamed: C32.1, U2.3, Y1.2
unnamed: D2.1, R22.2, U1.7
unnamed: D3.2, D4.2, D5.1, F1.1, Q2.3
unnamed: D4.1, Q1.2, Q2.1, R15.1
unnamed: D5.2, P1.3, R2.I2
unnamed: D6.1, P2.2
unnamed: D6.2, P2.1
unnamed: D10.2, R45.1, R48.1
unnamed: D8.1, D11.1, R42.1
unnamed: D12.2, R50.1, U7.8
unnamed: D13.1, D15.2
unnamed: D13.2, D14.2, R57.2
unnamed: D16.2, K1.1, Q4.3
unnamed: F1.2, P1.2
unnamed: IC1.2, U2.12
unnamed: IC1.7, X1.3
unnamed: IC1.8, X1.1
unnamed: IC1.30, U5.2
unnamed: IC1.31, U5.3
unnamed: J1.2, U6.18
unnamed: J1.3, U6.19
unnamed: K1.3, P2.5
unnamed: K1.4, K1.5
unnamed: K1.6, P2.4
unnamed: P1.1, R12.1, VR2.1
unnamed: P1.4, R14.1, VR1.1
unnamed: Q1.1, R11.2
unnamed: Q3.1, R31.2
unnamed: Q3.3, R29.2
unnamed: Q4.1, R37.2
unnamed: Q5.1, R40.1
unnamed: Q6.1, R39.1
unnamed: Q7.2, R49.1
unnamed: Q8.1, R53.1
unnamed: Q8.3, R55.2, R56.1
unnamed: Q9.1, R55.1
unnamed: R1.2, R3.1
unnamed: R2.E1, R24.2
unnamed: R2.E2, U8.3
unnamed: R3.2, R4.1, U7.3
unnamed: R6.2, R7.1, U7.6
unnamed: R8.2, U6.4
unnamed: R9.2, R12.2, U1.12
unnamed: R21.1, U1.8, U1.9
unnamed: R24.1, R25.2, U8.2
unnamed: R27.2, R28.1, R29.1, U9.1
unnamed: R28.2, R30.1
unnamed: R32.2, R33.1, U10.1
unnamed: R34.2, R35.1, U11.1
unnamed: R35.2, R36.1
unnamed: R41.1, R47.2, U13.1
unnamed: R41.2, R45.2, U13.3
unnamed: R42.2, R43.2, U12.3
unnamed: R44.1, R46.1, U7.10
unnamed: R44.2, U7.13, U7.14
unnamed: R46.2, U14.2, U14.6
unnamed: R47.1, U12.2
unnamed: R50.2, R51.1, U7.9
unnamed: U2.7, U7.1, U7.2
unnamed: U4.3, U7.5
unnamed: U5.6, U6.12
unnamed: U5.7, U6.10
unnamed: U6.2, X2.1
unnamed: U6.3, X2.3
SetVPlus: IC1.10, R31.1
USBGND: C14.2, C15.2, C16.2, C17.2, J1.5, U5.5, U6.20, X2.2
VCC: C5.1, C18.1, C26.1, C33.1, Q1.3, Q8.2, R10.1, R27.1, R57.1, U1.4, U7.4, U9.2, U11.3, U13.5
VRelay: IC1.11, R37.1
VSet: R6.1, U1.3, U7.7
VUSB: C14.1, C15.1, C16.1, J1.1, R8.1, U5.8, U6.1
Voutmon: R1.1, R13.1, R17.2, R19.2, U1.14, U7.12
Vprereg: C24.1, C25.1, D3.1, D10.1, Q2.2, Q5.2, Q6.2, R23.1
Vrect+: D6.4, D7.1, D9.1, Q5.3, Q6.3, R38.1
Vrect-: C1.2, C2.2, C3.2, C4.2, C5.2, C6.2, C7.2, C8.2, C9.2, C10.2, C11.2, C12.2, C13.2, C18.2, C19.2, C24.2, C25.2, C26.2, C27.2, C28.2, C30.2, C31.2, C32.2, C33.2, C34.2, D7.4, D15.1, IC1.3, IC1.5, IC1.21, ICSP.6, Q3.2, Q4.2, Q9.2, R2.I1, R4.2, R7.2, R9.1, R15.2, R23.2, R30.2, R33.2, R36.2, R48.2, R49.2, R51.2, R52.2, R56.2, U1.11, U2.10, U2.16, U3.4, U4.4, U4.16, U5.4, U7.11, U8.4, U12.1, U13.2, U14.4, X1.2

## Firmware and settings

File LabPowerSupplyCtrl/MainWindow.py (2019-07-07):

#!/usr/bin/env python3

import sys
from kivy.app import App
from kivy.properties import ObjectProperty
from kivy.uix.boxlayout import BoxLayout
from kivy.core.window import Window

from PowerSupplyChannel import PowerSupplyChannel
from FanController import FanController
import PowerInputControl
from ChannelControl import ChannelControl

class ControlWindow(BoxLayout):
    channel1 = ObjectProperty(None)
    channel2 = ObjectProperty(None)
    channel3 = ObjectProperty(None)

    def bind_channels(self,fan_controller):
        try:
            print("Inside bind_channels")
            self.psuChannel1 = PowerSupplyChannel(
                1,"/dev/ttyACM0","28-0415b237afff")
            print("Starting channel1")
            self.psuChannel1.start()
            self.psuChannel2 = PowerSupplyChannel(
                2,"/dev/ttyACM1","28-0415b24bc8ff")
            print("Starting channel2")
            self.psuChannel2.start()
            self.psuChannel3 = PowerSupplyChannel(
                3,"/dev/ttyACM2","28-0315b24341ff")
            print("Starting channel3")
            self.psuChannel3.start()

            self.channel1.bind_to_psu(self.psuChannel1,1,fan_controller,self)
            self.channel2.bind_to_psu(self.psuChannel2,2,fan_controller,self)
            self.channel3.bind_to_psu(self.psuChannel3,3,fan_controller,self)

            self.start_updates()
        except:
            print("Unexpected error:", sys.exc_info()[0])
            raise

    def start_updates(self):
      self.channel1.start_updates()
      self.channel2.start_updates()
      self.channel3.start_updates()

    def stop_updates(self):
      self.channel1.stop_updates()
      self.channel2.stop_updates()
      self.channel3.stop_updates()

    def shutdown(self):
        if self.psuChannel1 is not None:
            self.psuChannel1.stop()
        if self.psuChannel2 is not None:
            self.psuChannel2.stop()
        if self.psuChannel3 is not None:
            self.psuChannel3.stop()

class ButtonSlice(BoxLayout):
    pass

class LabPowerSupplyCtrlApp(App):

    def __init__(self):
        App.__init__(self)
        self.control_window = None

    def build(self):
        self.control_window = ControlWindow()
        self.fan_controller = FanController()
        self.control_window.bind_channels(self.fan_controller)
        Window.full_screen = 1
        return self.control_window

    def shutdown(self):
       if self.control_window is not None:
           self.control_window.shutdown()


if __name__ == '__main__':
    app = LabPowerSupplyCtrlApp()

    def closeStuff(signum,stack):
        app.shutdown()
        PowerInputControl.turnOffSupply()

    try:
        PowerInputControl.turnOnSupply()
        #signal.signal(signal.SIGINT,closeStuff)
        #signal.signal(signal.SIGHUP,closeStuff)
        app.run()
    except:
        print("Unexpected error:", sys.exc_info()[0])
        raise
    finally:
        app.shutdown()
        PowerInputControl.turnOffSupply()

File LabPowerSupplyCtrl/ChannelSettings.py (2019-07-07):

import configparser
import os

class ChannelSettings():
    SECTION_NAME="ChannelSettings"

    def __init__(self,channelNumber):
        print("Inside ChannelSettings")
        self.channelNumber = channelNumber
        self.config = configparser.ConfigParser()
        config_file = self._make_file_name()
        print("Checking file "+config_file+" exists")
        config_exists = os.path.isfile(config_file)
        print("Config file exists = "+str(config_exists))
        if config_exists:
            print("Reading config from file")
            self.config.read(config_file)
        if not self.config.has_section(self.SECTION_NAME):
            print("Adding "+self.SECTION_NAME)
            self.config[self.SECTION_NAME] = {}
        print("Leaving ChannelSettings __init__")

    def _make_file_name(self):
        return os.path.expanduser("~/.labpschannel"+str(self.channelNumber)+".cfg")

    def _save(self):
        with open(self._make_file_name(),'w') as config_file:
            self.config.write(config_file)

    def set_voltage(self,voltage):
        self.config[self.SECTION_NAME]["Voltage"] = str(voltage)
        self._save()

    def get_voltage(self):
        voltage = 10.0 
        try:
            voltage = float(self.getValue("Voltage"))
        except configparser.NoOptionError:
            pass
    
        if not (0.0 < voltage <= 30.0 ):
            voltage = 10.0

        print("Init settings have voltage = "+str(voltage));
        return voltage

    def set_current(self,current):
        self.config[self.SECTION_NAME]["Current"] = str(current)
        self._save()

    def get_current(self):
        current = 1.0
        try:
            current = float(self.getValue("Current"))
        except configparser.NoOptionError:
            Pass

        if not (0.0 < current <= 4.8):
            current = 1.0

        print("Init settings have current = "+str(current));
        return current

    def getValue(self,key):
        if key in self.config[self.SECTION_NAME]:
            return self.config[self.SECTION_NAME][key]
        else:
            return "0.0"

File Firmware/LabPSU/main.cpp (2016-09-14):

/*
 * LabPSU.cpp
 *
 * Created: 7/1/2015 9:06:16 PM
 *  Author: tom
 */ 

#define F_CPU 20000000

#include <avr/io.h>

#include <util/delay.h>

//#include "AD5689DAC.h"
#include "SerialSetup.h"
#include "CommandInterpreter.h"
#include "LabPSU.h"

#include "stdio.h"
#include "string.h"
#include "util/delay.h"

int freeRam () 
{
    extern int __heap_start, *__brkval;
    int v;
    return (int) &v - (__brkval == 0 ? (int) &__heap_start : (int) __brkval);
}

int main(void)
{
    SerialSetup serialSetup;
    //printf("Tom's Lab Power Supply\r\n");
    //printf("Free ram is %d\r\n",freeRam());
    
    LabPSU      psu;
    //printf("Free ram is %d\r\n",freeRam());

    CommandInterpreter  commandInterpreter(&psu);
    //printf("Free ram is %d\r\n",freeRam());
    
    _delay_ms(500.0);
    //printf("Calling Init\r\n");

    psu.init();
    //printf("Init Complete\r\n");
    psu.setOutputVoltageLimit(10.0f);
    psu.setCurrentLimit(1.0f);
    
    //int i=0;
    
    //while(1)
    //{
    //    printf("1 fish %d fish\r\n",i++);
    //}
    
    
    while(1)
    {
        commandInterpreter.processNextCommand();
    }        
}

extern "C" void __cxa_pure_virtual()
{
	printf("Pure Virtual called! I'm outa here!\r\n");
}

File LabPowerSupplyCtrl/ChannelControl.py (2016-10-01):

from kivy.properties import ObjectProperty
from kivy.clock import Clock
from kivy.config import Config
from kivy.uix.boxlayout import BoxLayout

from CalibratePopup import CalibratePopup
from CalibrateProgressPopup import CalibrateProgressPopup
from Calibrator import Calibrator

from NumericalValuePopup import NumericalValuePopup

__author__ = 'tom'


class ChannelControl(BoxLayout):

    set_voltage=ObjectProperty(30.0)
    set_current=ObjectProperty(3.0)
    output_voltage=ObjectProperty(30.0)
    output_current=ObjectProperty(3.0)
    temperature=ObjectProperty(25.0)

    enabled = ObjectProperty(False)
    in_current_limit = ObjectProperty(False)

    def enable_clicked(self,instance,value):
        if self.channel.is_connected():
            self.channel.enable(value);

    def set_voltage_callback(self,instance):
        if self.channel.is_connected() and instance.get_value() is not None:
            self.channel.set_set_voltage(instance.get_value())
        self.control_window.start_updates();
        return False

    def set_current_callback(self,instance):
        if self.channel.is_connected() and instance.get_value() is not None:
            self.channel.set_set_current(instance.get_value())
        self.control_window.start_updates();
        return False

    def set_voltage_clicked(self):
        self.control_window.stop_updates();
        view = NumericalValuePopup()
        #view.set_value(self.set_voltage)
        view.set_current_mode(False)
        view.bind(on_dismiss=self.set_voltage_callback)
        view.open()
        pass

    def set_current_clicked(self):
        self.control_window.stop_updates();
        view = NumericalValuePopup()
        #view.set_value(self.set_current)
        view.set_current_mode(True)
        view.bind(on_dismiss=self.set_current_callback)
        view.open()
        pass

    def calibrate_clicked(self):
        view = CalibratePopup(self)
        view.bind(on_dismiss=self.calibrate_chosen)
        view.open()

    def calibrate_chosen(self,instance):
        if instance.get_calibration_type() is not None:
            self.control_window.stop_updates()
            self.channel.pause(True)
            view = CalibrateProgressPopup(self.channel,instance.get_dmm_ip(),instance.get_calibration_type())
            view.bind(on_dismiss=self.calibrate_complete)
            view.open()

    def calibrate_complete(self,instance):
        self.channel.pause(False)
        self.control_window.start_updates();

    def bind_to_psu(self,channel,channel_number,fan_controller,control_window):
        self.channel = channel
        self.channel_number = channel_number
        self.fan_controller = fan_controller
        self.control_window = control_window

    def update_from_channel(self,dt):
        if self.channel.is_connected():
            set_voltage = self.channel.get_set_voltage()
            if self.set_voltage != set_voltage:
                self.set_voltate = set_voltage
            self.set_voltage = self.channel.get_set_voltage()
            self.set_current = self.channel.get_set_current()
            self.output_current = self.channel.get_output_current()
            self.output_voltage = self.channel.get_output_voltage()
            self.in_current_limit = self.channel.in_cc_mode()
            self.enabled = self.channel.is_enabled()

        return True

    def update_temperature(self,dt):
        if self.channel.is_connected():
            self.temperature = self.channel.get_temperature()
            self.fan_controller.set_temp(self.temperature,self.channel_number)
        return True

    def start_updates(self):
        Clock.schedule_interval(self.update_from_channel,0.25)
        Clock.schedule_interval(self.update_temperature,10)

    def stop_updates(self):
        Clock.unschedule(self.update_from_channel)
        Clock.unschedule(self.update_temperature)

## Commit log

2015-12-15 Initial commit of KiCAD files and readme
    [DigitalControl.sch, KiCAD.sch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]
2015-12-16 Implemented output enable and command to check if we are in current limit mode
2015-12-16 Wrong port thing for CC mode. Also made it so always not in CC mode when disabled
    [LabPSU.cpp]
2015-12-30 Split into files. Experimented with a yellow border (still needs work). Added Code to interface with the actual power supply and added unit test for power supply interface code
2016-03-10 Re-enabled the ADC, got rid of some printfs and added a command to set the output from a count value (for calibration)
2016-03-16 ADC Cal table updated. Added command to get ADC count (for calibration)
2016-04-05 More GUI work and bug fixes
    [MainWindow.py]
2016-04-06 Added Calibration code based on PowerSupplyChannel
2016-04-19 Started re-design of PCB. Schematic changes from testing first board and started developing new layout
    [DigitalControl.sch, Power.sch, PreRegulator.sch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]
2016-04-29 Missing files
    [ModularLabPSU.kicad_pcb]
2016-05-20 Added Linearizer for current ADC/DAC. Added some cal data to see how good the current reading is
2016-05-21 More work on calibration code
2016-07-07 Added KiCAD project for power input control and added (start of) PI soft-switch project
    [PiPower.kicad_pcb, PiPower.sch, PowerInput.kicad_pcb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]
2016-08-10 Completed PiPower board design
    [PowerButton.kicad_pcb, PowerButton.sch]
2016-08-22 Raspberry Pi Power control board
    [PiPower.kicad_pcb, PiPower.sch]
2016-08-22 Missed a couple of stars on precision resistors
    [DigitalControl.sch, VoltageAndCurrentControl.sch]
2016-08-31 Added temperature sensing and temperate display. Added fan control based on temperature. All three channels added
2016-09-01 Changed PowerSupplyChannel to be async (i.e. thread). Still testing. TBD
2016-09-02 More work on running the channel interface in a thread
2016-09-02 Fixed switch callback
2016-09-03 Work on Calibrate GUI
2016-09-06 More work on Calibrator GUI
2016-09-14 Added more meat to calibrate code
2016-09-14 Changed the way the dialogs communicate so cancelation is handlded better. Fixed a few bugs
    [CalibratePopup.py, Calibrator.py, ChannelControl.py]
2016-09-15 Added code to make calibration commands respond
2017-04-25 Fixed settings saving code so it will use home directory
    [ChannelSettings.py]
2017-05-17 Fixed a case-sensitivity issue that stopped the schematic opening on Linux
    [ModularLabPSU.sch]
2017-09-06 Added PDFs of Schematics
2018-06-16 Changes to add more resoluition at low voltages/currents
